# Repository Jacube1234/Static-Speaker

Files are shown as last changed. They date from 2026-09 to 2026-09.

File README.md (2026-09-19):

# Static-Speaker


<br>
View PCB on KiCanvas

<a href="">
  Youtube Demo
</a>

This is my custom radio combined with a speaker designed for the YSWS Static
I chose this project to upgrade the standard kit by integrating an M18 Bluetooth module alongside the original RDA5807 FM radio chip, transforming it into a permanent Bluetooth speaker for my bedroom while keeping the physical over-the-air FM radio chip!

## Features:
- Bluetooth audio streaming directly from a phone
- Over-the-air local FM Radio playback
- One physical push-button to switch modes
- Dual analog potentiometers for volume control

## CAD Model:

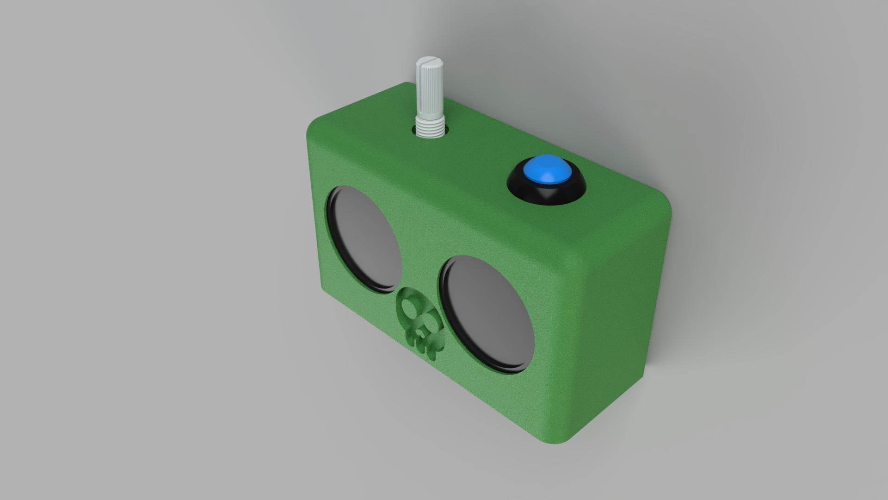
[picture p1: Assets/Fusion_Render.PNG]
CAD Model


## PCB

Schematic

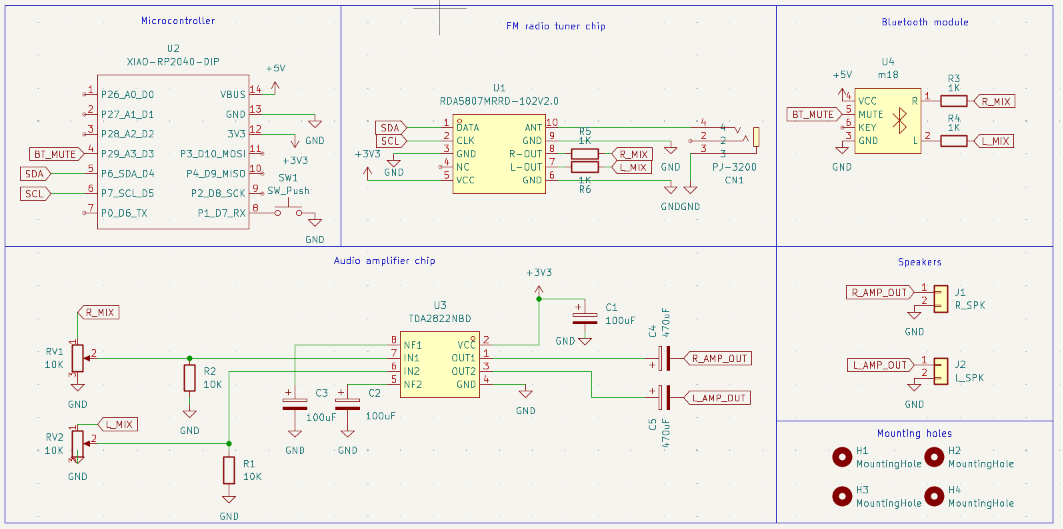
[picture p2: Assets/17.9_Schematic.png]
Schematic


Layout

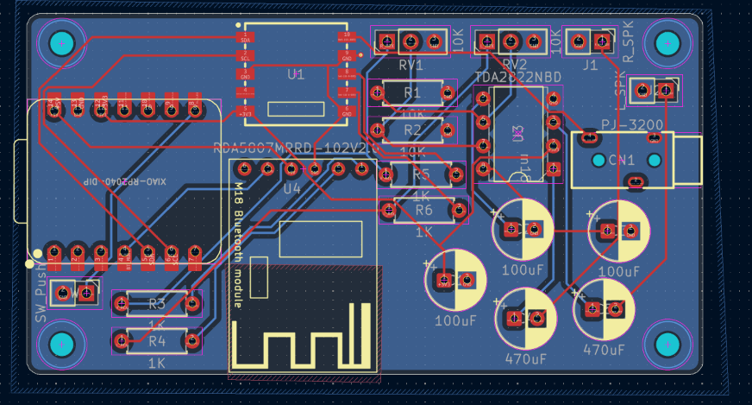
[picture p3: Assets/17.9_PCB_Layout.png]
Layout of PCB


PCB

3D Viewer

## Firmware Overview
Runs on CircuitPython using an RDA5807 library wrapper. A `code.py` script handles I2C tuning for the FM radio, manages the M18 module's mute line via pin A3 (`BT_MUTE`), and toggles between Bluetooth and FM sources using a push button (`SW1`).

## File structure

There's 3 main folders: Firmware, PCB, and Production. The PCB folder contains .kicad_pcb, .kicad_pro, and .kicad_sch. The Firmware folder contains files for the Seeed Xiao code. The production folder will have files for the PCB printing.

## BOM (Bill of Materials):
Here should be everything you need to make this speaker
Most things should be what static sends you except the bluetooth module.

- 1x Seeed Studio XIAO RP2040
- 1x MH-M18 Bluetooth Audio Module
- 1x RDA5807FP FM Radio Tuner Chip
- 1x TDA2822 Audio Amplifier Chip
- 1x WH148 10kΩ Potentiometer
- 4x 1kΩ Resistors 
- 1x 3.5mm Jack (for FM Radio Antenna)
- 2x 10uF Capacitors
- 2x 100uF Capacitors
- 2x 30mm Speakers
- 1x 12mm Momentary Push Button Mode switch
- Hookup wire (for off-board connections)
- 1x Custom PCB

## Software

- Kicad recommended to view the Gerber files or the general `.pcb` `.pro` `.sch` files
- Thonny or VSCode for programming the board.

## Tools:

- Soldering Iron
- Solder

## How to build/replicate
1. **Gather Parts:** Get **everything** that is on the BOM.
2. **Solder the PCB:** Solder all components onto your custom PCB using a soldering iron.
3. **Print & Mount Case:** 3D print your enclosure design, then mechanically secure and screw the potentiometers (`RV1`/`RV2`) and push button (`SW1`) into place.
4. **Wire Peripherals:** Wire your speakers to `J1` and `J2`, and plug a cable into the 3.5mm jack (`CN1`) to serve as the FM antenna.
5. **Flash Firmware:** Install **CircuitPython** onto your Seeed XIAO RP2040.
6. **Add Code Files:** Copy the `RDA5807.py` library and your `code.py` script directly onto the board's `CIRCUITPY` drive.
7. **Power Up & Test:** Connect USB power (+5V). Pair your phone via Bluetooth to the M18 module or press the push button (`SW1`) to switch over to FM radio mode.
8. **Enjoy:** Adjust your volume knobs and enjoy your custom speaker!

## Extra stuff
In Hackpad style -
Hi guys

Bye guys

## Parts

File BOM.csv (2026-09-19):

Reference | Qty | Value | DNP | Exclude from BOM | Exclude from Board | Footprint | Datasheet
C1,C2,C3 | 3 | 100uF |  |  |  | Capacitor_THT:CP_Radial_D6.3mm_P2.50mm
C4,C5 | 2 | 470uF |  |  |  | Capacitor_THT:CP_Radial_D6.3mm_P2.50mm
CN1 | 1 | PJ-3200 |  |  |  | Static:AUDIO-TH_PJ-3200 | https://www.lcsc.com/datasheet/C2689690.pdf
J1 | 1 | R_SPK |  |  |  | Connector_PinHeader_2.54mm:PinHeader_1x02_P2.54mm_Vertical
J2 | 1 | L_SPK |  |  |  | Connector_PinHeader_2.54mm:PinHeader_1x02_P2.54mm_Vertical
R1,R2 | 2 | 10K |  |  |  | Resistor_THT:R_Axial_DIN0207_L6.3mm_D2.5mm_P7.62mm_Horizontal
R3,R4,R5,R6 | 4 | 1K |  |  |  | Resistor_THT:R_Axial_DIN0207_L6.3mm_D2.5mm_P7.62mm_Horizontal
RV1,RV2 | 2 | 10K |  |  |  | Connector_PinHeader_2.54mm:PinHeader_1x03_P2.54mm_Vertical
SW1 | 1 | SW_Push |  |  |  | Connector_PinHeader_2.54mm:PinHeader_1x02_P2.54mm_Vertical
U1 | 1 | RDA5807MRRD-102V2.0 |  |  |  | Static:RDA5807 | https://www.lcsc.com/datasheet/C9900205627.pdf
U2 | 1 | XIAO-RP2040-DIP |  |  |  | Static:XIAO-RP2040-DIP
U3 | 1 | TDA2822NBD |  |  |  | Package_DIP:DIP-8_W7.62mm | https://www.lcsc.com/datasheet/C51927337.pdf
U4 | 1 | m18 |  |  |  | Static:m18 | https://www.sunrom.com/download/705.pdf

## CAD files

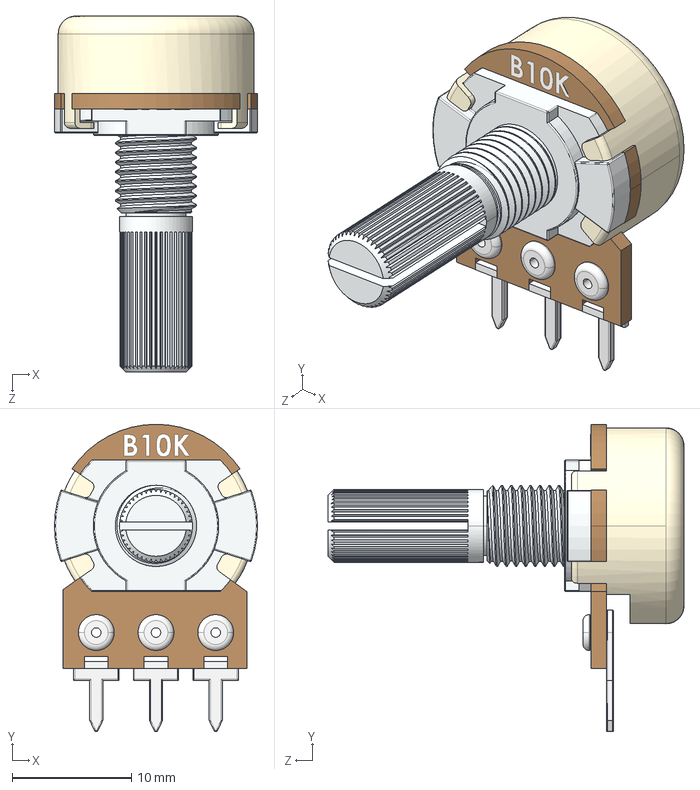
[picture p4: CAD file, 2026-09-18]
Assets/Components/10K.STEP
17.0 x 25.7 x 29.8 mm
Peça1^Potenciometro
Peça2^Potenciometro
Peça3^Potenciometro
Peça5^Potenciometro
Peça6^Potenciometro x 3

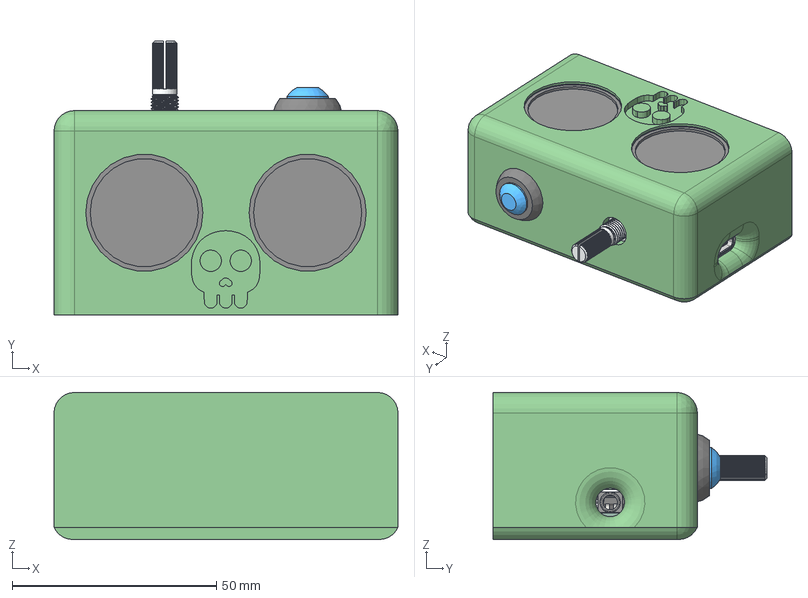
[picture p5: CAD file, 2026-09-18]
CAD/Final/Speaker design.step
84.2 x 67.0 x 36.0 mm
12mm Push Button Amazon
CUI_DEVICES_CMS-305-158SP-67 x 2
Peça6^Potenciometro x 3
Peça5^Potenciometro
Peça3^Potenciometro
Peça1^Potenciometro
Peça2^Potenciometro
Potentiometer
CP_Radial_D63mm_P250mm x 5
R_Axial_DIN0207_L63mm_D25mm_P762mm_Horizontal x 6
DIP-8_W7.62mm_1
PinHeader_1x03_P254mm_Vertical x 2
COMM-SMD_L11.0-W11.0-P2.00-TL_1
type-c v2
smd_button v3
DOUT
DIN
VSS
VDD
smd_button v3(Mirror)
mh-m18_1
RESC-0402.stp x 5
CAPC-0402-T0.55-BN.stp x 8
CAPC-0805-T0.75-BN.stp
Flat.stp
Pins.stp
LED-0805h1.1.stp
SC-76A.stp
SSOPxL-150-0.64_24L-150-0.64-Default
PinHeader_1x02_P254mm_Vertical x 3
AUDIO-TH_PJ-3200_1
Radio-Speaker_PCB

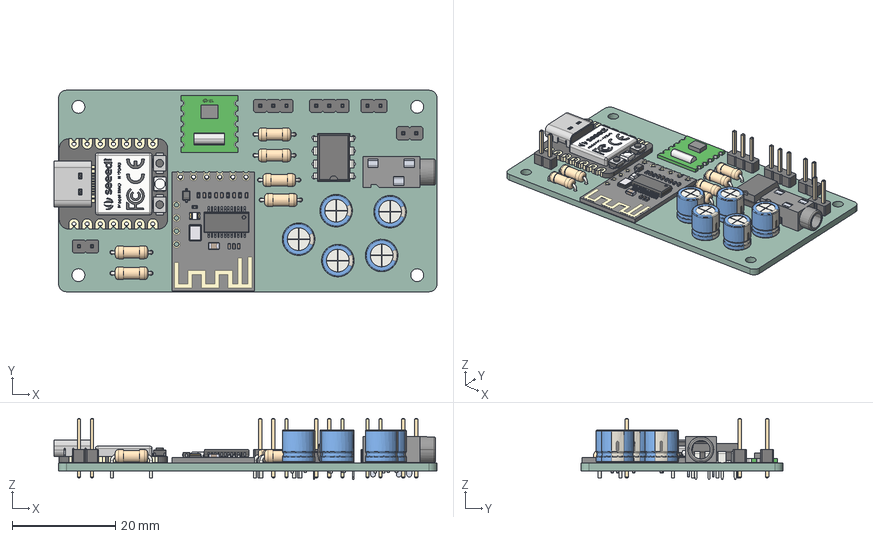
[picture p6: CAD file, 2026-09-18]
CAD/PCB/PCB.step
74.1 x 39.0 x 11.8 mm
CP_Radial_D63mm_P250mm x 5
R_Axial_DIN0207_L63mm_D25mm_P762mm_Horizontal x 6
DIP-8_W7.62mm
PinHeader_1x03_P254mm_Vertical x 2
COMM-SMD_L11.0-W11.0-P2.00-TL
type-c v2
smd_button v3
DOUT
DIN
VSS
VDD
smd_button v3(Mirror)
mh-m18
RESC-0402.stp x 5
CAPC-0402-T0.55-BN.stp x 8
CAPC-0805-T0.75-BN.stp
Flat.stp
Pins.stp
LED-0805h1.1.stp
SC-76A.stp
SSOPxL-150-0.64_24L-150-0.64-Default
PinHeader_1x02_P254mm_Vertical x 3
AUDIO-TH_PJ-3200
Radio-Speaker_PCB

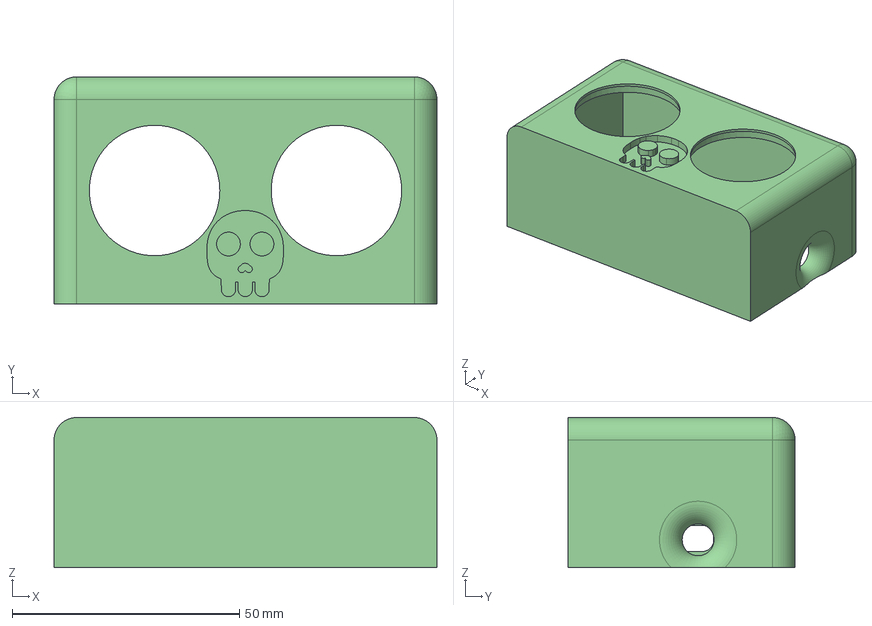
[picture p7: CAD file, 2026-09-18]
Production/Body.step
84.2 x 50.0 x 33.0 mm

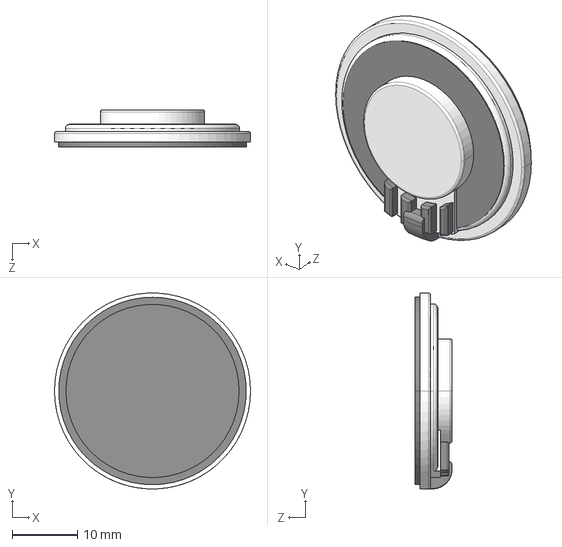
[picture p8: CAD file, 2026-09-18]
Assets/Components/Speaker.step
30.0 x 30.0 x 5.70 mm

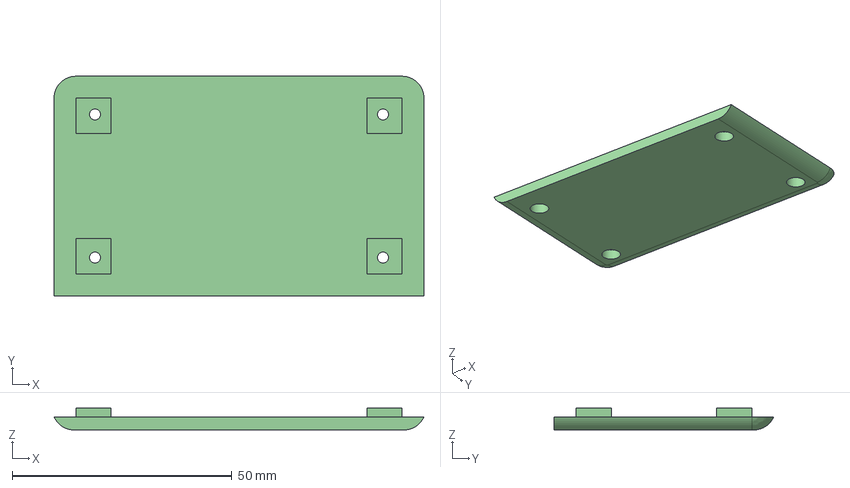
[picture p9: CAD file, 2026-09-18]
Production/Base.step
84.2 x 50.0 x 5.00 mm

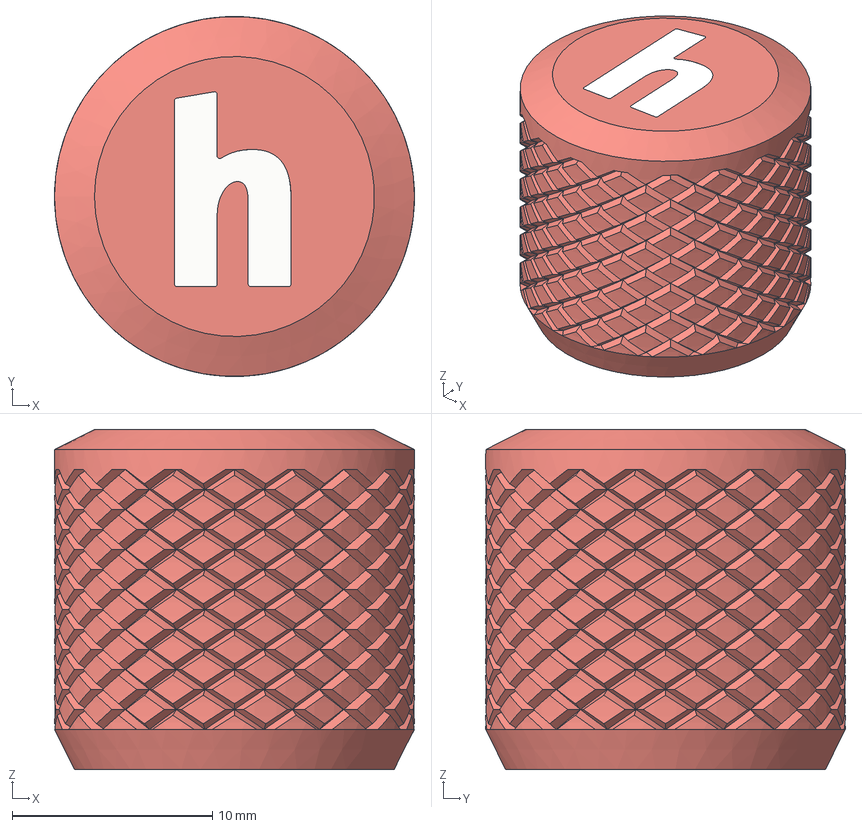
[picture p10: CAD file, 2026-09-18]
Assets/Components/Hack Club Knurled Knob.step
18.0 x 18.0 x 17.0 mm
Base
H

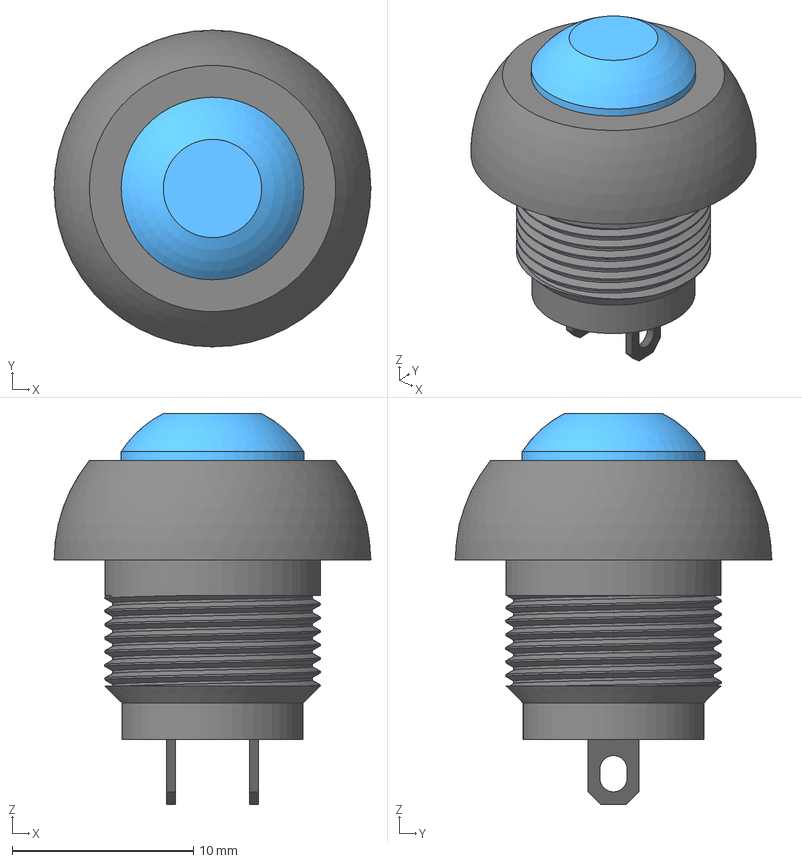
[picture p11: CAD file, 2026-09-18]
Assets/Components/12mm Push Button.step
17.5 x 17.5 x 21.6 mm

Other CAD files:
CAD/Final/Speaker design.3mf
CAD/Final/Speaker design.f3z

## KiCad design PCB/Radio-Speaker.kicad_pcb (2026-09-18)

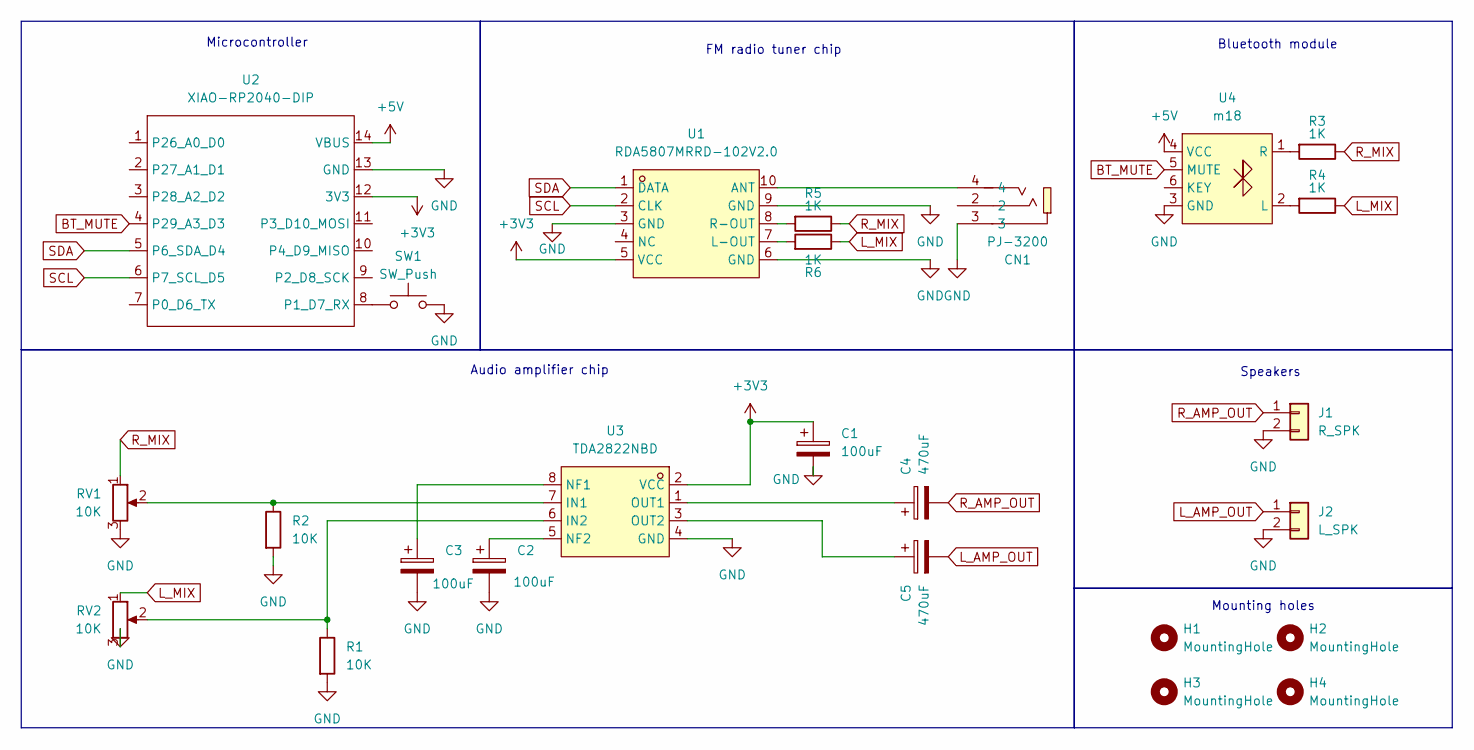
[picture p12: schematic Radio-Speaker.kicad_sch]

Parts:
C1, C2, C3: 100uF; CP_Radial_D6.3mm_P2.50mm
C4, C5: 470uF; CP_Radial_D6.3mm_P2.50mm
CN1: PJ-3200; AUDIO-TH_PJ-3200; MPN PJ-3200; LCSC Part C2689690
H1, H2, H3, H4: MountingHole; MountingHole_2.5mm
J1: R_SPK; PinHeader_1x02_P2.54mm_Vertical
J2: L_SPK; PinHeader_1x02_P2.54mm_Vertical
R1, R2: 10K; R_Axial_DIN0207_L6.3mm_D2.5mm_P7.62mm_Horizontal
R3, R4, R5, R6: 1K; R_Axial_DIN0207_L6.3mm_D2.5mm_P7.62mm_Horizontal
RV1, RV2: 10K; PinHeader_1x03_P2.54mm_Vertical
SW1: SW_Push; PinHeader_1x02_P2.54mm_Vertical
U1: RDA5807MRRD-102V2.0; RDA5807; MPN RDA5807MRRD-102V2.0; LCSC Part C9900205627
U2: XIAO-RP2040-DIP
U3: TDA2822NBD; DIP-8_W7.62mm; MPN TDA2822NBD; LCSC Part C51927337
U4: m18

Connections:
+3V3: C1.1, U1.5 (VCC), U2.12 (3V3), U3.2 (VCC)
+5V: U2.14 (VBUS), U4.4 (VCC)
BT_MUTE: U2.4 (P29_A3_D3), U4.5 (MUTE)
GND: C1.2, C2.2, C3.2, CN1.3, J1.2, J2.2, R1.2, R2.2, RV1.3, RV2.3, SW1.2, U1.3 (GND), U1.6 (GND), U1.9 (GND), U2.13 (GND), U3.4 (GND), U4.3 (GND)
L_AMP_OUT: C5.2, J2.1
L_MIX: R4.1, R6.1, RV2.1
unnamed: CN1.4, U1.10 (ANT)
unnamed: R6.2, U1.7 (L-OUT)
unnamed: R5.2, U1.8 (R-OUT)
unnamed: SW1.1, U2.8 (P1_D7_RX)
unnamed: R2.1, RV1.2, U3.7 (IN1)
unnamed: R1.1, RV2.2, U3.6 (IN2)
unnamed: C3.1, U3.8 (NF1)
unnamed: C2.1, U3.5 (NF2)
unnamed: C4.1, U3.1 (OUT1)
unnamed: C5.1, U3.3 (OUT2)
unnamed: R4.2, U4.2 (L)
unnamed: R3.2, U4.1 (R)
R_AMP_OUT: C4.2, J1.1
R_MIX: R3.1, R5.1, RV1.1
SCL: U1.2 (CLK), U2.6 (P7_SCL_D5)
SDA: U1.1 (DATA), U2.5 (P6_SDA_D4)

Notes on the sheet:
Audio amplifier chip
Mounting holes
Bluetooth module
Speakers
FM radio tuner chip
Microcontroller

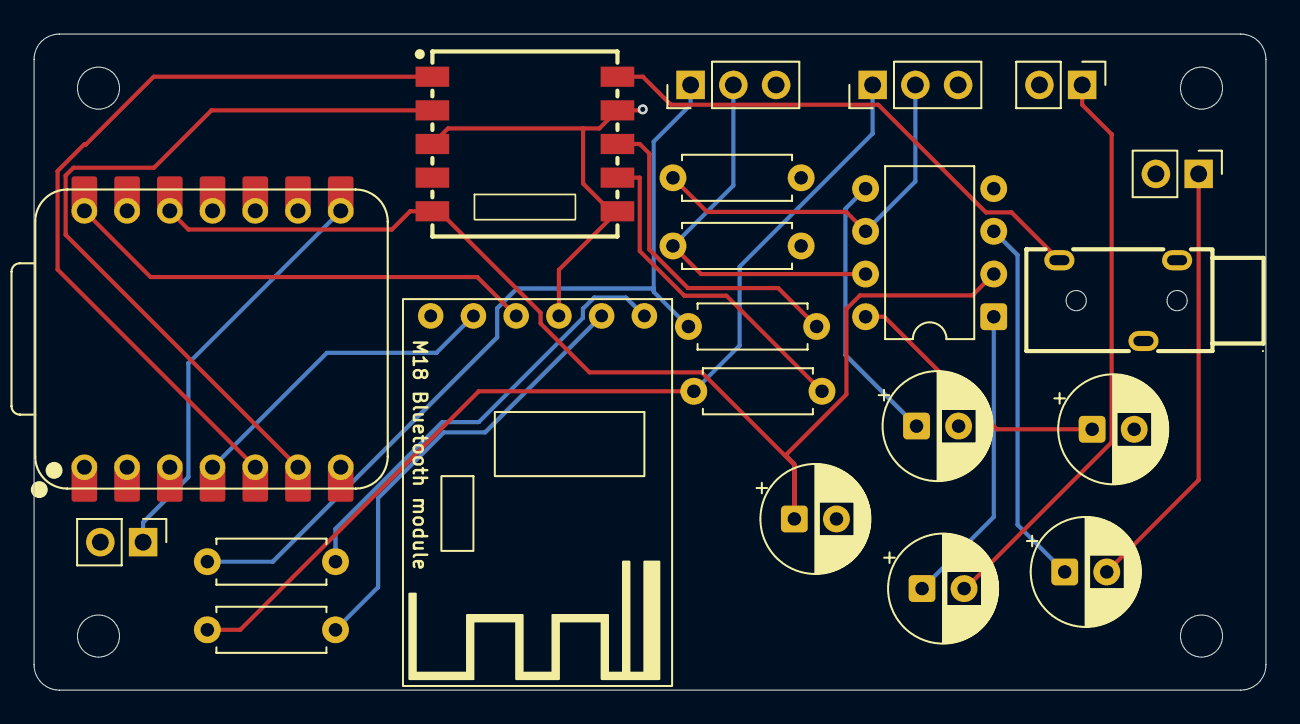
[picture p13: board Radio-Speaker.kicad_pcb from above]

Board: 2 copper layers, 73.2 x 39.0 mm, 25 parts (0 on the bottom side), 22 nets.

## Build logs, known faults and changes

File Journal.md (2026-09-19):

# Journal

I am building this custom speaker because I want to upgrade the standard Hack Club Static kit by adding an MH-M18 Bluetooth module. I want it to be a permanent Bluetooth speaker for my bedroom, but I also want to keep the actual over-the-air FM radio chip from the original kit so I can toggle between wireless streaming and local radio.

## 12 September 2026 - Dropping Parts into KiCad & Checking Layout

Today I started actually placing the main component blocks onto my KiCad schematic screen to match the original setup before modifying it for the Seeed XIAO RP2040 integration. 

I managed to place the original XIAO microcontroller block, the RDA5807 FM radio chip, the 3.5mm jack socket (which acts as our antenna), and the TDA2822 amplifier block, wiring up basic power rails and ground symbols. I’m taking it slow and double-checking pinouts against the official guide to avoid silly mistakes later. 

I ran into a bit of confusion with the capacitors because I wasn't entirely sure at first whether I needed to pick specific physical footprints or just rename the values (like sorting out the 10uF and 100uF caps). Once I figured out the footprint matching, the next step became clearing up those capacitor values and wrapping up the rest of the core schematic blocks.

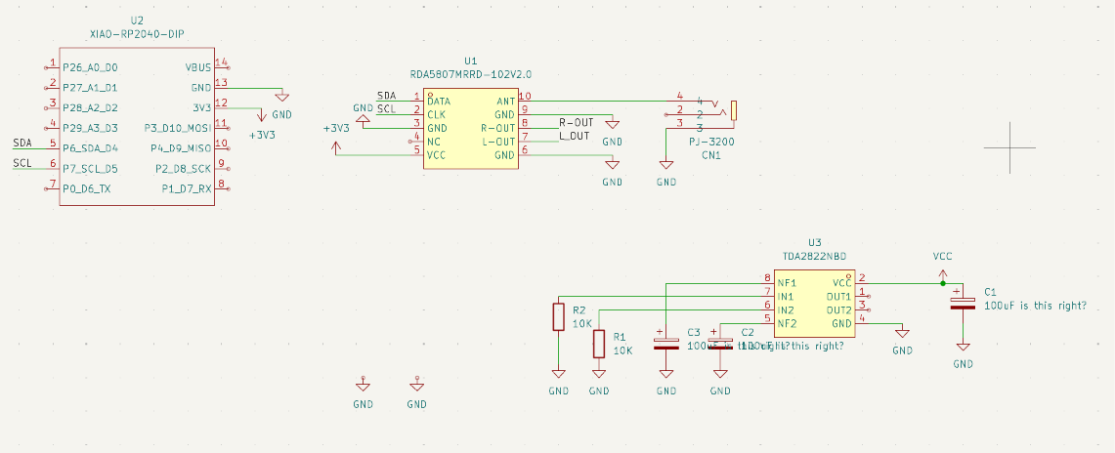
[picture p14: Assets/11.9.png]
Screenshot of my early KiCad schematic progress


### Time Spent: 2 Hours

---

## 13 September 2026 - Setting Up GitHub

Today I worked on getting my project files properly backed up and organised online using GitHub Desktop. 

I ran into some folder structure issues at first because the desktop app tried to track unrelated temporary cache files and auto-generated editor backups. I had to set up a clean folder hierarchy (`Firmware`, `PCB`, `Production`) and filter out the clutter. Now everything is cleanly organised into folders for the KiCad project files, the Seeed XIAO code, and the future manufacturing outputs.

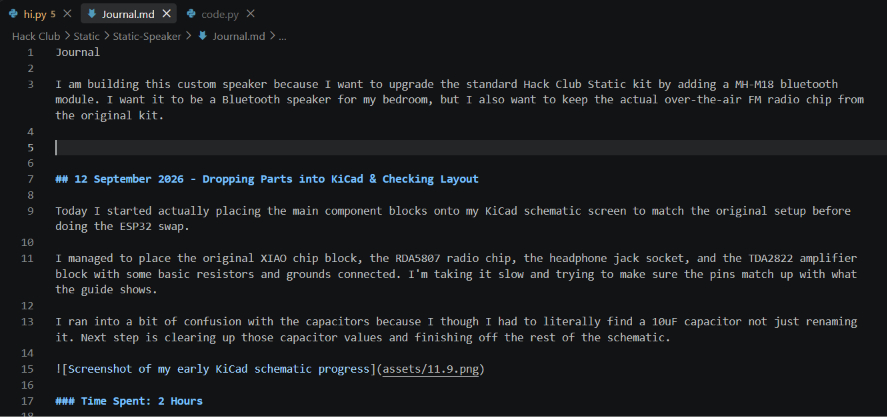
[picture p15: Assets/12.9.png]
Markdown writting


### Time Spent: 1.5 Hours

---

## 14 September 2026 - Integrating the Bluetooth Module & Audio Mixing

Today I tackled the core modification of the project: adding the MH-M18 Bluetooth audio module into my schematic so I can stream music straight from my phone.

Since the MH-M18 isn't in standard base KiCad libraries, I had to download and link a custom community symbol and footprint so it showed up correctly instead of a generic header. I wired up its 5V power and ground lines, and then tackled the tricky part—combining the audio streams. 

If you just wire two audio outputs together, they'll short each other out and cause major distortion. With some AI guidance, I designed a passive summing network: I added a 1kΩ resistor to every single audio output line coming from both the Bluetooth module and the RDA5807 FM radio chip. This merges them safely into shared `R_MIX` and `L_MIX` lines before hitting the amplifier, ensuring the two source paths don't mess each other up. Since the volume potentiometers and speakers are mounted offboard, I added clean pin headers and connector pads to route the mixed audio out to them.

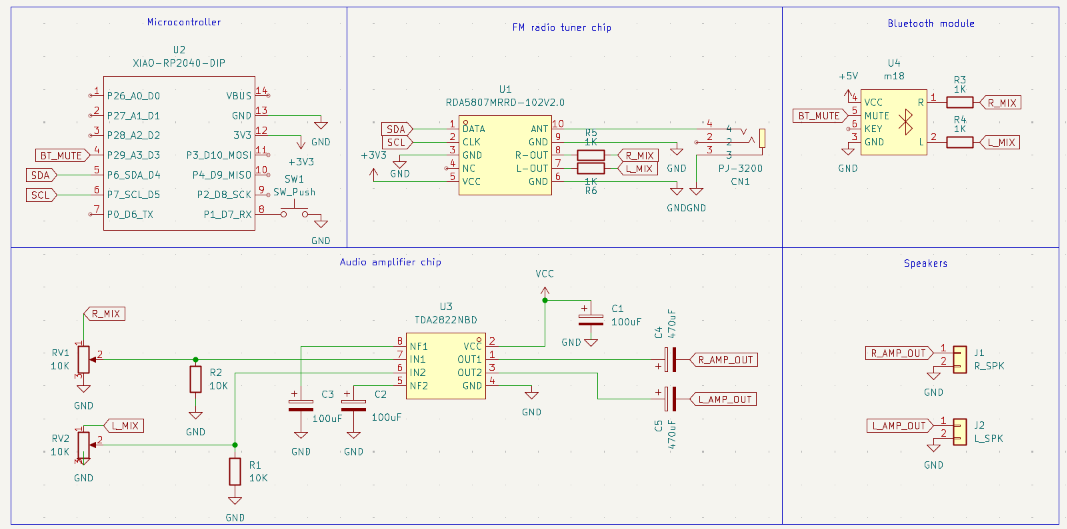
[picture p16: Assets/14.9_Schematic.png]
Schematic


After that, I started grouping components on the layout editor. I organised them logically from left to right following the natural power and signal flow through the circuit—keeping the amplifier and its power filtering capacitors closely clustered together to minimise noise.

### Time Spent: 2 Hours

---

## 15 September 2026 - Fixing Schematic & Optimising Net Labels

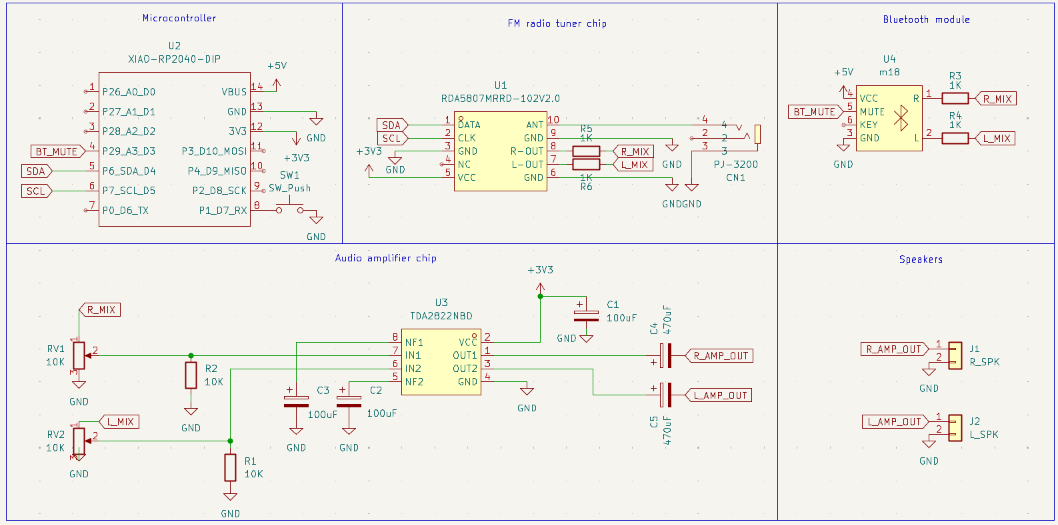
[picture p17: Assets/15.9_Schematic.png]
Schematic


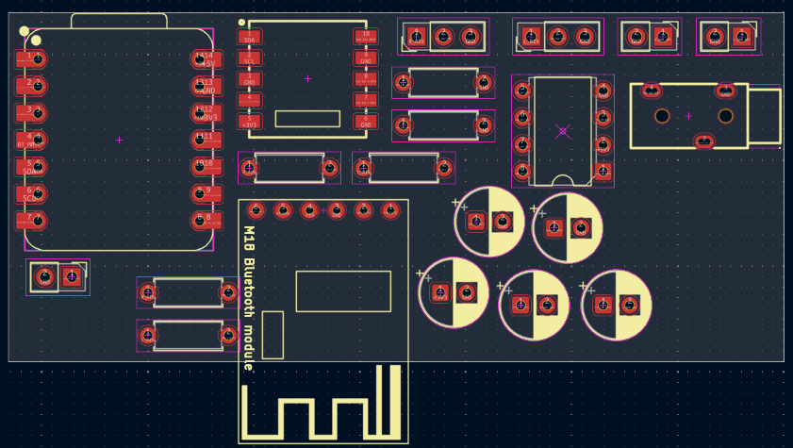
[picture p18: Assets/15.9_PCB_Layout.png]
PCB Layout


Today I cleaned up several power and net label issues. I changed generic VCC labels to an explicit `+5V` net to match the power input requirements and ensure the XIAO gets a clean supply. 

I also adjusted how the MH-M18 Bluetooth module sits on the edge of the board. I wanted to make sure its onboard antenna section hangs slightly off or clear of dense ground pours so the board traces don't block or interfere with the wireless Bluetooth signal.

### Time Spent: 1 Hour

---

## 16 September 2026 - PCB Routing and DRC Clearance

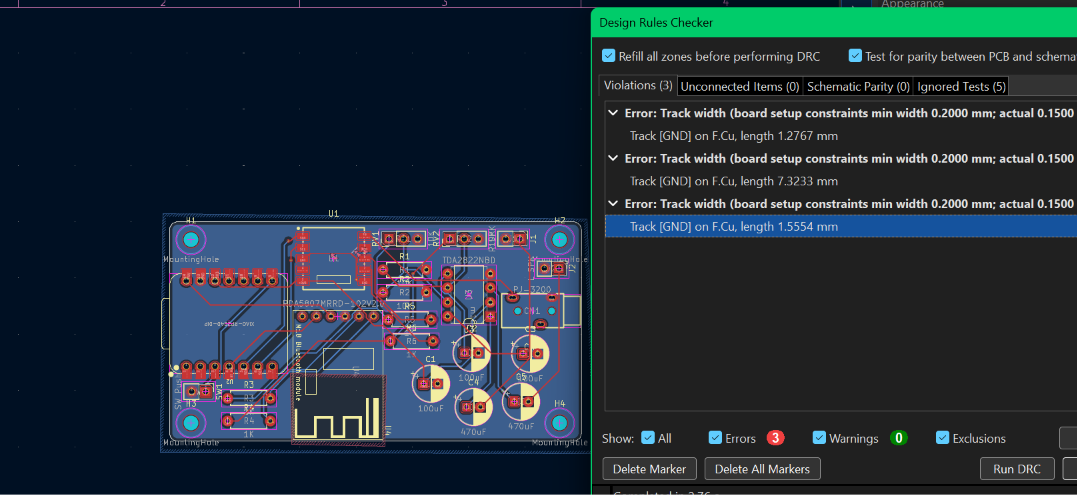
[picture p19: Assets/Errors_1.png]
Errors 1


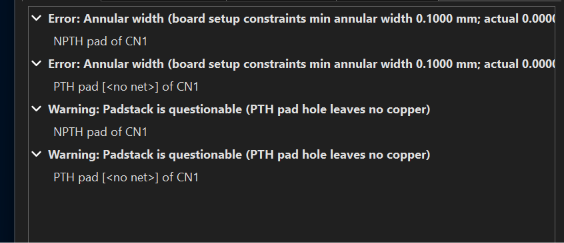
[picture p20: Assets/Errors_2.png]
Errors 2


Today was all about refining the physical board layout and clearing errors. 

I re-laid out parts of the board so the Bluetooth module is securely mounted without awkwardly hanging off, making it much easier to design a solid mechanical enclosure around it later. This led to a bunch of Design Rule Check (DRC) errors—mostly track clearance issues and overlapping silkscreen text. Working through them one by one, I carefully routed traces around the audio lines to prevent electrical noise coupling into the amplifier. I also made extra sure the Bluetooth module's antenna region remained entirely clear of ground plane fills and copper traces to protect wireless performance.

### Time Spent: 3 Hours

---

## 17 September 2026 - 3D Viewer Validation

3D Viewer

Today I ran a complete 3D View check to inspect the fully assembled board layout. 

This step is super helpful because it lets you catch physical collisions before spending money on manufacturing. I confirmed clean component seating, verified that the pin headers for the offboard potentiometers, speakers, and push button have enough physical clearance, and checked that everything lines up nicely for a future enclosure fit.

The images below show the final cleaned schematic and layout from yesterday's session that I took today.
Schematic
PCB Layout

### Time Spent: 1 Hour

---

## 18 September 2026 - Gerber Exports & CAD Enclosure Modelling

Today I finished preparing the board for production and started designing the physical case. 

For the board export, I configured KiCad's plot settings to generate a clean manufacturing package consisting strictly of copper layers, solder mask, silkscreen, and the board outline (`Edge.Cuts`). 

With the PCB layout locked in, I jumped into CAD (Fusion 360). I imported the 3D model of the board and all major offboard components (speakers, volume pots, and control buttons wired through pin connectors) into a hybrid assembly so I could design a custom, snugly-fitted 3D-printable case around the hardware layout with proper screw standoffs and wire routing paths.

CAD Model

### Time Spent: 1.5 Hours

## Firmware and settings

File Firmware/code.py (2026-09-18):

import time
import board
import digitalio
from rda5807 import RDA5807

# --- 1. Hardware Pin Setup ---
# Bluetooth Mute control connected to XIAO pin A3 (P29)
bt_mute = digitalio.DigitalInOut(board.A3)
bt_mute.direction = digitalio.Direction.OUTPUT

# Mode toggle button connected to SW1 (XIAO pin D8)
mode_button = digitalio.DigitalInOut(board.D8)
mode_button.direction = digitalio.Direction.IN
mode_button.pull = digitalio.Pull.UP

# --- 2. Initialize FM Radio ---
print("Initializing FM Radio chip...")
radio = RDA5807()
radio.set_volume(10)  # Volume scale: 0 to 15

# --- 3. Startup State ---
# Start in Bluetooth mode by default
bluetooth_mode = True
bt_mute.value = False  # False / LOW enables the M18 Bluetooth module audio

print("System Ready!")
print(" -> Current Mode: Bluetooth (Pair your phone to 'M18' or 'BT5.0')")
print(" -> Press the push button (SW1) to switch to FM Radio.")

last_button_state = mode_button.value

while True:
    current_button_state = mode_button.value
    
    # Detect button press (falling edge because of pull-up resistor)
    if last_button_state and not current_button_state:
        bluetooth_mode = not bluetooth_mode
        
        if bluetooth_mode:
            print("\n[Mode Switched] -> Bluetooth Active")
            bt_mute.value = False  # Unmute Bluetooth audio
        else:
            print("\n[Mode Switched] -> FM Radio Active")
            bt_mute.value = True   # Mute Bluetooth audio so it doesn't overlap
            radio.tune(92.1)       # Tune to your local station (change 99.5 as needed)
            
        # Short debounce delay
        time.sleep(0.3)
        
    last_button_state = current_button_state
    time.sleep(0.05)

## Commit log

2026-09-12 Made kicad
    [Radio-Speaker.kicad_pcb, Radio-Speaker.kicad_sch]
2026-09-14 PCB work
    [Radio-Speaker.kicad_pcb, Radio-Speaker.kicad_sch]
2026-09-18 LOTS of new stuff
    [10K.STEP, 12mm Push Button.step, Hack Club Knurled Knob.step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]
2026-09-18 Production verisons of case
    [Base.step, Body.step]
2026-09-19 Improved both .md files
    [Hackpad schematic.csv]
2026-09-19 Added cad model to readme
2026-09-25 renamed to BOM
    [BOM.csv]
